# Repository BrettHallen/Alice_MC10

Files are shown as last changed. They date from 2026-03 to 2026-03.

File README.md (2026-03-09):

# Purpose
Simple designs for the Tandy TRS-80 MC-10 and Matra Alice.<br>

This boldly red computer is a French version of the Tandy MC-10 using the same Motorola 6803 CPU clocked at 890KHz and using the same MC6847 Video Display Generator (VDG).<br>

It was built by French companies Matra and Hachette but seems to be commonly known simply as the "Matra Alice".<br>

## YouTube Videos
- [Part 1: First Look](https://youtu.be/JoOMIVsprkE)
- [Part 2: Keyboard Problem](https://youtu.be/W2BdekgW1rA)
- [Part 3: Tandy TRS-80 MC-10 Comparison](https://youtu.be/A9SVZOl3z24)
- [Part 4: Keyboard Fixed & Internal 8KB RAM Upgrade](https://youtu.be/OvdkhOnV7no)

## RGB Video Pinout
- Pin 1 = n/c
- Pin 2 = ground
- Pin 3 = red
- Pin 4 = synch
- Pin 5 = green
- Pin 6 = audio
- Pin 7 = blue

I had to tweak variable resistor R45 in the video output stage to get a stable image.<br>

It appears to adjust the level of Field Sync. and Horizontal Sync. signals coming out of the MC6487 VDG.<br>

## [DIN-to-VGA Adapator](/DIN_To_VGA)
A simple adaptor board to take the 7-pin DIN output (via a 7-pin DIN male-to-male cable) and convert to a VGA socket & 3.5mm audio socket.<br>

## [Internal 4KB-to-8KB RAM Upgrade](/Internal_8KB_RAM)
Upgrade the Alice or MC-10 internal RAM from 4KB to 8KB.  Note that the extra 4KB isn't available if the 16KB expansion is also attached.<br>

BUT ... check out the expander below as there is a version that should work with the 8KB upgrade.<br>

## [RGB Video Modification](/RGB_Video) (Work In Progress)
Convert the MC-10 video output from RF modulated to RGB - design is based on the Matra Alice.<br>

## [Expander](https://github.com/Fred72z/ALICE)
Check out [Fred72z's](https://github.com/Fred72z) excellent expansion for Alice & MC10 ... RAM, joysticks, cartridge.

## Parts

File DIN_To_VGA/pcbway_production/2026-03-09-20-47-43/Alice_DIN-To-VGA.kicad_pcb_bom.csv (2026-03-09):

Designator | Quantity | Value | Footprint | Package | MPN | DNP | Mount_Type | Description | Height | Manufacturer_Name | Mouser Part Number | Mouser Price/Stock
J1 | 1 | Matra Alice | 6710801 |  | 671-0801 |  | tht | Deltron 8 Pole Right Angle Din Socket Socket, 2A, 100 V ac, Lockable | 19.5 | DELTRON COMPONENTS
J2 | 1 | VGA Out | DSUB-15-HD_Socket_Horizontal_P2.29x2.54mm_EdgePinOffset8.35mm_Housed_MountingHolesOffset10.89mm |  |  |  | tht | 15-pin D-SUB connector, socket (female), High density (3 columns), Triple Row, Generic, VGA-connector
J3 | 1 | Audio Out | SJ3350820BTR |  | SJ3-350820B-TR |  | tht | 3.5 mm Stereo Jack, Through Hole, 2 Conductors, 1 Internal Switches, Tape & Reel Packaging | 5.3 | Same Sky | 179-SJ3-350820B-TR | https://www.mouser.co.uk/ProductDetail/Same-Sky/SJ3-350820B-TR?qs=IKkN%2F947nfBCsohFK16iQg%3D%3D

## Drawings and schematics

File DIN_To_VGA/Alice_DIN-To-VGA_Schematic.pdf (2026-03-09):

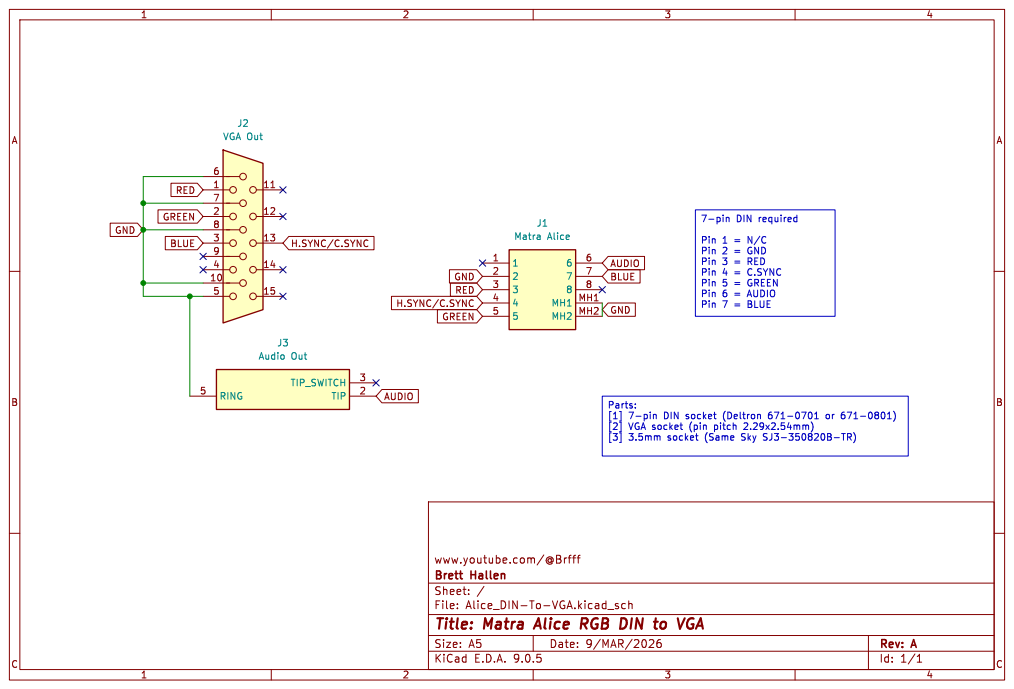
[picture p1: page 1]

www.youtube.com/@Brfff
Sheet: /
File: Alice_DIN-To-VGA.kicad_sch
Title: Matra Alice RGB DIN to VGA

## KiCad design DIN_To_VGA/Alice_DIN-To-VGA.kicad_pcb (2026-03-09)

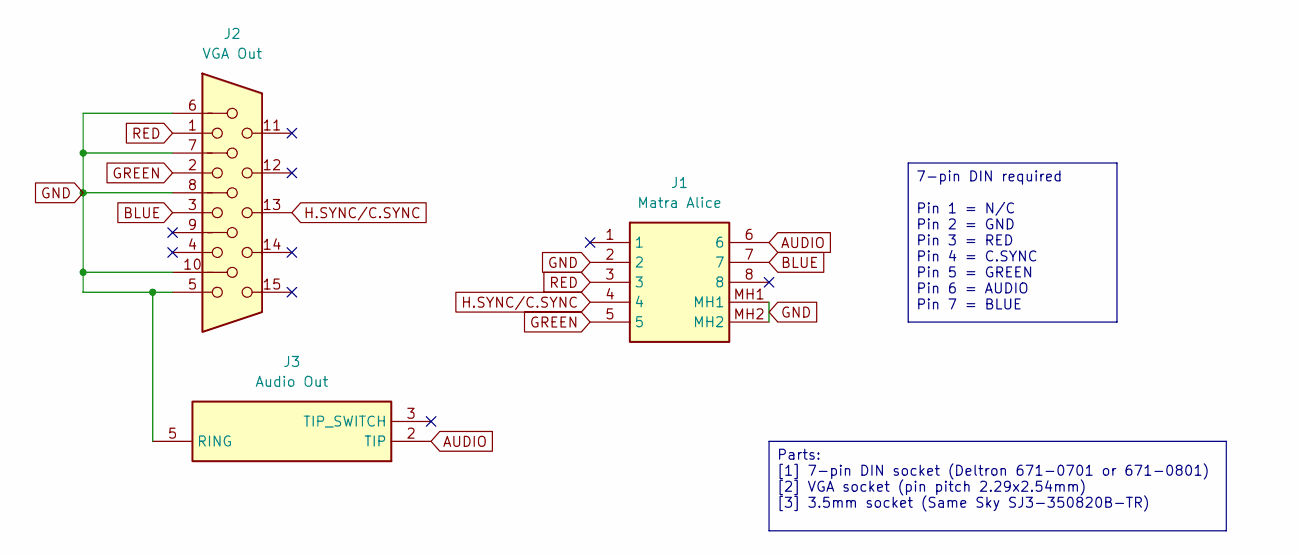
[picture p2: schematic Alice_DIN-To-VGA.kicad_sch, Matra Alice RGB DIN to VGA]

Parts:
J1: Matra Alice; 6710801; Manufacturer_Part_Number 671-0801
J2: VGA Out; DSUB-15-HD_Socket_Horizontal_P2.29x2.54mm_EdgePinOffset8.35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
J3: Audio Out; SJ3350820BTR; Mouser Part Number 179-SJ3-350820B-TR

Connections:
AUDIO: J1.6, J3.2 (TIP)
BLUE: J1.7, J2.3
GND: J1.2, J1.MH1, J1.MH2, J2.5, J2.6, J2.7, J2.8, J2.10, J3.5 (RING)
GREEN: J1.5, J2.2
H.SYNC/C.SYNC: J1.4, J2.13
RED: J1.3, J2.1
V.SYNC: J2.14

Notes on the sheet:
Parts: [1] 7-pin DIN socket (Deltron 671-0701 or 671-0801) [2] VGA socket (pin pitch 2.29x2.54mm) [3] 3.5mm socket (Same Sky SJ3-350820B-TR)
7-pin DIN required Pin 1 = N/C Pin 2 = GND Pin 3 = RED Pin 4 = C.SYNC Pin 5 = GREEN Pin 6 = AUDIO Pin 7 = BLUE

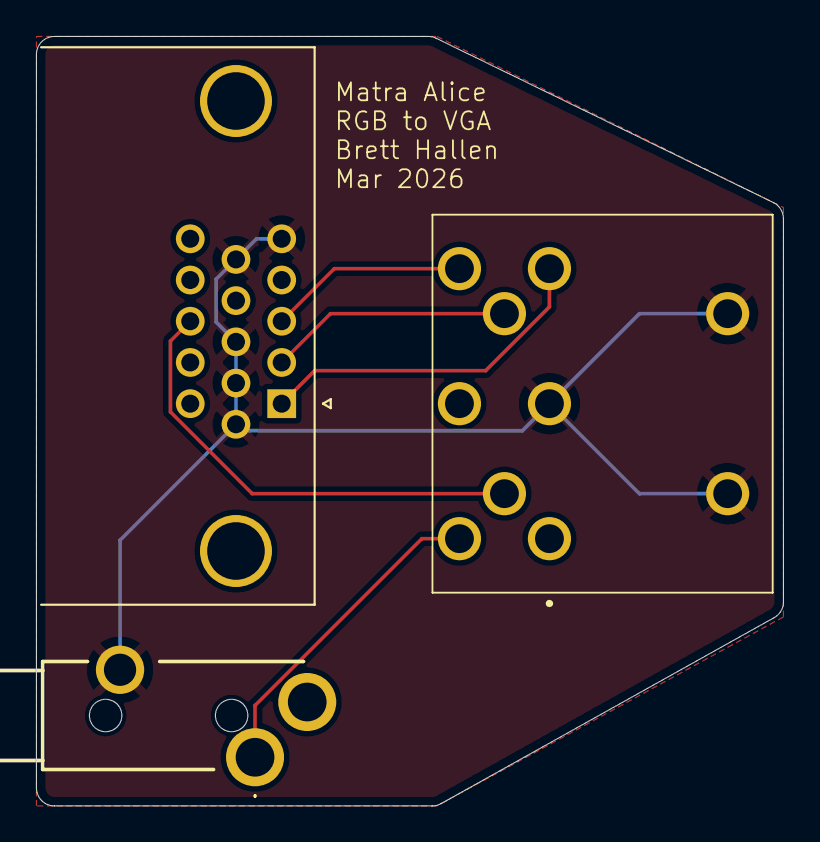
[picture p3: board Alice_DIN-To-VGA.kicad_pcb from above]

Board: 2 copper layers, 41.5 x 42.8 mm, 3 parts (0 on the bottom side), 6 nets.
